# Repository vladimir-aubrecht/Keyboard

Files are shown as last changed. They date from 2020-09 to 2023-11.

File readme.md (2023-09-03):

# Keyboard overview
As usual, I started with this project because I couldn't find keyboard I'd like to use.

This project is trying to build following:
- :white_check_mark: TKL hotswap keyboard for Cherry MX switches.
- :white_check_mark: RGB LEDs under each switch (individually controllable from connected device).
- :white_check_mark: Bluetooth 5.0.
- :white_check_mark: Charging through USB-C.
- :construction: Anodized aluminium frame of Filco Majestouch 2 design.
- :white_check_mark: Part of case with connector is removable & replacable (to replace either connector or whole microcontroller for any other).

Side features:
- :white_check_mark: Except of sockets & connectors for connecting to MCU everything is on front side for soldering on JCLPCB side.
- :white_check_mark: Modularity - All logic chips are on separate modules. Main PCB contains just RGB LEDs, sockets and IO expanders with LED drivers.

❤️ I have some spare PCBs based on Revision 1 & 2. <br/>
**I will donate 1 piece of PCB per person** (develiry paid by you). Be aware, that it's just PCB, components must be soldered by you.

# Current status
[Revision 2](changelog.md) PCB is working, check details about the [rev 2 build](docs/revisions/rev2.md) and [manual](./docs/manual.md)!

I am finishing validation of adjusted casing and planning aluminium manufacturing soon.

If you are interested in more granular updates, I created [this Discord channel](https://discord.com/channels/1029883759740334140/1029884160967442452) where I'll be posting status, photos, ideas, etc.

## Achievements
- :zap: It's fast. In [Joltfly test](./docs/images/joltfly_rev_1.png) I got 0 ms latency. My internal measurements are 500 microseconds.
- :high_brightness: It's bright. RGB LED lights are well visible even during the daylight.

# Next steps
Polishing firmware is main focus. It's working, but there is a lot of technical debt there due to support of multiple microcontrollers for testing.
I started to work on [QMK support](https://github.com/vladimir-aubrecht/qmk_firmware/tree/xboard/keyboards/xboard).

For more details on long term plans you can check this [document](./docs/future.md).

TKL from top
TKL from detail

Check more [photos](./docs/gallery.md)! :)

# Credits

- [Jakub](https://www.printables.com/@null) for printing case for me on Prusa XL so I can have it in single piece :)

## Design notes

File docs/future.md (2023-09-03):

# Future plans

## Short term
### QMK
- Rev 1 keyboard is working now with QMK firmware, but bluetooth is not functional as when BT is enabled, keyboard scanning stop to work for some reason (will follow up on it).
- Rev 2 firmware in progress.

## Long term
- adding status LEDs or tiny colorful display (if I find some which fits into existing space, this is preferable solution).
- switch for turning keyboard on and off
- better microcontroller with USB-C and more program storage
- gyroscope / accelerometer for movement detection for optimizing wake up experience
- fingerprint sensor

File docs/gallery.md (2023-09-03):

# Galery

## Revision 2
Keyboard Top
TKL from top

Keyboard detail
TKL from detail

Numpad from angle
Numpad from angle

Numpad from top
Numpad from top

## Revision 1
Reality top cover
Case top cover

Reality top white LEDs
Case top white LEDs

Reality top colorfull LEDs
Case top colorfull LEDs

Reality back
Case back

Reality back connector
Case back connector

Keyboard
Keyboard

Reality front random colors
PCB reality front random colors

Reality front
PCB reality front

Render
Case render

Render no plate
case render no plate

Render no pcb
case render no pcb

Render no cover
case render no cover

Render front
PCB render front

Render back
PCB render back

Reality Plate
Plate reality

Render
Plate render

Scheme
PCB scheme

Reality front
PCB reality front

Reality back
PCB reality back

Reality numpad with LEDs on
PCB reality LEDs

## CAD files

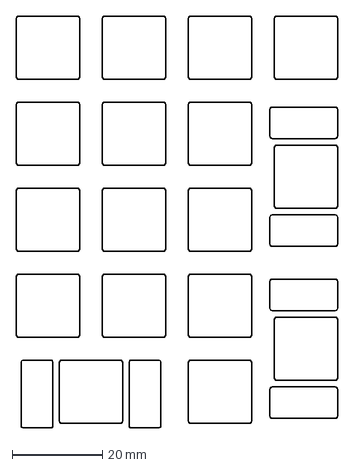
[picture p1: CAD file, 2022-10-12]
frame/numpad plate.dxf
71.1 x 91.2 mm

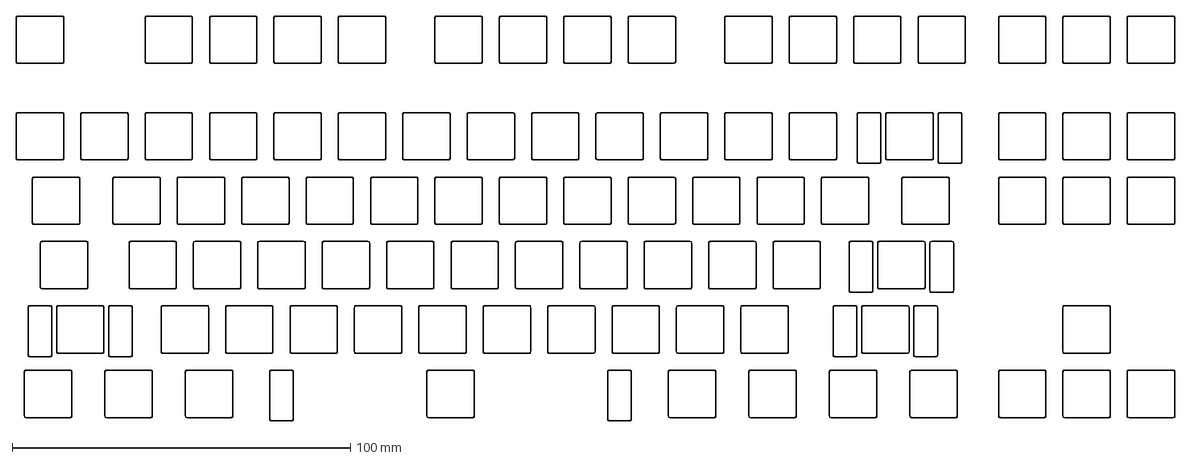
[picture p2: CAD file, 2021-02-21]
frame/plate.dxf
342.6 x 119.8 mm

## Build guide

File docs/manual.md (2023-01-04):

# Manual

## Bluetooth
For pairing the keyboard first [reset original pairing](#shortcuts), pair it with the device and then [switch to Bluetooth](#shortcuts).

Keyboard will be named as XBoard during the pairing.

When switching between USB and Bluetooth, you'll see which input channel is selected by blinking key.

<table>
    <tr>
        <th>Selected channel</th>
        <th><center>USB</center></th>
        <th><center>Bluetooth</center></th>
    </tr>
    <tr>
        <th>Key</th>
        <td>F1</td>
        <td>F2</td>
    </tr>
</table>

## Battery
Battery charge is visualised on Fkey line after pressing the [shortcut](#Shortcuts). Data will be shown as follow:

<table>
    <tr>
        <th>Key</th>
        <th><center>F1</center></th>
        <th><center>F2</center></th>
        <th><center>F3</center></th>
        <th><center>F4</center></th>
        <th><center>F5</center></th>
        <th><center>F6</center></th>
        <th><center>F7</center></th>
        <th><center>F8</center></th>
        <th><center>F9</center></th>
        <th><center>F10</center></th>
        <th><center>F11</center></th>
    </tr>
    <tr>
        <th>Battery [%]</th>
        <td>10</td>
        <td>20</td>
        <td>30</td>
        <td>40</td>
        <td>50</td>
        <td>60</td>
        <td>70</td>
        <td>80</td>
        <td>90</td>
        <td>100</td>
        <td>Keyboard is powered by USB</td>
    </tr>
</table>

When battery drops under 15%, then keyboard turns red.

## Shortcuts

| **Action** | **Shortcut** |
| :---: | :---: |
| Bluetooth Pairing Reset | Ctrl + Win + Esc |
| Toggle LED on/off | Ctrl + Win + F1  |
| Switch between USB / Bluetooth | Ctrl + Win + F2  |
| Randomize LEDs colors | Ctrl + Win + F3  |
| Show battery status | Ctrl + Win + F4  |

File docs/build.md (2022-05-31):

# Revisions

- [Revision 1](./revisions/rev1.md)
- [Revision 2](./revisions/rev2.md) (Work in progress)

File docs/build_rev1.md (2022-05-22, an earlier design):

# Build
This repository contains all necessary artefact to build the keyboard.

Meaning:
- PCB
- [List of components](#List-of-components)
- [Firmware](#Firmware) for [Adafruit Feather Bluefruit 32u4 LE](https://www.adafruit.com/product/2829) (read about [improvements](#future-improvements)!)
- [Plate](#Plate)
- Frame (not done yet)

> :warning: Revision 1 had originally bug with 2 swapped wires for power supply for IO expanders. That's why PCB in galery has those 2 wires and it was fixed in latest commits.

## Dimensions
- Plate: 343x119 mm
- PCB: 349x128 mm

## List of components for PCB
LCSC numbers are based on [JLCPCB](http://jlcpcb.com/) catalog.

| Type | Name | LCSC | Package | Amount | Description | 
| --- | --- | --- | --- | --- | --- |
| Diods | [1N4148WT](https://datasheet.lcsc.com/szlcsc/1908191708_MDD-Microdiode-Electronics-1N4148WT_C414017.pdf) | C414017 | SOD-523 |  87 | Preventing key ghosting & masking effects. |
| RGB LED | [19-237/R6GHBHC-A04/2T](https://datasheet.lcsc.com/szlcsc/2010222107_Everlight-Elec-19-237-R6GHBHC-A04-2T_C883183.pdf) | C883183 | 19-237  |  87 | Light under each switch. |
| IO Expanders | [MCP23017-E/SO](https://datasheet.lcsc.com/szlcsc/Microchip-Tech-MCP23017-E-SO_C47023.pdf) | C47023  | SOIC-28 | 2 | Connecting rows & columns from switch matrix through I2C. |
| LED Driver | [IS31FL3743A](https://cz.mouser.com/datasheet/2/198/IS31FL3743A_DS-1949512.pdf) | N/A | QFN-40  | 2 | Addressing LED and controlling RGB LED diods through I2C. |
| Hotswap sockets | [Kailh sockets](https://www.kailhswitch.com/info/kailh-switch-pcb-hot-swapping-socket-33463528.html) | N/A | N/A |  87 | Connecting Cherry MX switches |
| Stabilizers | [Cherry stabilizers](https://www.aliexpress.com/item/32951252318.html) | N/A | N/A | 5 | Stabilizing long keycaps. |
| Capacitor 1uF | [CL05A105KA5NQNC](https://datasheet.lcsc.com/szlcsc/Samsung-Electro-Mechanics-CL05A105KA5NQNC_C52923.pdf) | C52923  | 0402 | 4 | Stabilizing power circuit for LED drivers. |
| Resistor 10 KOhm  | [0402WGF1002TCE](https://datasheet.lcsc.com/szlcsc/Uniroyal-Elec-0402WGF1002TCE_C25744.pdf) | C25744  | 0402 | 6 | Controlling brightness & pull ups for IO expanders. |
| Resistor 4.7 KOhm | [0402WGF4701TCE](https://datasheet.lcsc.com/szlcsc/Uniroyal-Elec-0402WGF4701TCE_C25900.pdf) | C25900  | 0402 | 4 | Pull up resistor for LED drivers. |
| Resistor 200 Ohm  | [0402WGF2000TCE](https://datasheet.lcsc.com/szlcsc/Uniroyal-Elec-0402WGF2000TCE_C25087.pdf) | C25087  | 0402 |  12 | Green and blue LED channels to limit current and prevent overheating. |
| Resistor 150 Ohm  | [0402WGF1500TCE](https://datasheet.lcsc.com/szlcsc/Uniroyal-Elec-0402WGF1500TCE_C25082.pdf) | C25082  | 0402 | 6 | Red LED channel to limit current and prevent overheating. |

## Firmware
Custom made firmware (source code in repo) for [Adafruit Feather Bluefruit 32u4 LE](https://www.adafruit.com/product/2829). This has full feature set, keyboard functionality, RGB LEDs and Bluetooth are working.

Firmware is very simple to adjust (if needed at all) for other microcontrollers given microcontroller has required feature (USB HID, BT, I2C, 32 KB Program Storage - no need for all of them, you just need to comment USB HID or BT if your controller doesn't have it).

In Git history it's possible to find old version of firmware for QMK. It was working, but I don't maintain it anymore, thou it's possible to extend support if there will be enough of interest ...

## Plate
Built with the help of [Keyboard Layout Editor](http://www.keyboard-layout-editor.com/#/) & Keeb's Plate tool (https://plate.keeb.io/).

## Case
Built in OnShape CAD software, [check out](https://cad.onshape.com/documents/c60788452082993ff7acdd11/w/b14733d6a8d57351c8582e21/e/f5989423f9dc86a71831a4e9) the models!

## Future improvements
- Even thou RGB LED lights are working, **light intensity is quite low during the day light**. I am planning to play with global brightness resistor or switch to better LEDs.

- Adafruit Feather is working well, thou program storage is very limited - just 32 KB. Current version of firmware is using all of that and I had to comment out logging as didn't have enough of storage. It can be probably optimised more, my guess is to like 50-75% of current usage, but it will still be tight for more new features. I'll be switching to better microcontroller...

- Current combination of PCB chips is limiting I2C to 400 KHz and given amount of queries to MCP23017 there is a performance issue there. Latency of scanning is ~20 ms, **total latency ~30 ms** (through USB). Feeling wise I didn't have problem to type on it by using all my 10 fingers with quite fast speed, but I can imagine it might be **problematic for progamers**. Potential workaround around this is disconnecting RGB LEDs through the connector after which 1.7MHz on I2C should be available, potentially speeding it up.
In next version I am planning to switch to SPI.

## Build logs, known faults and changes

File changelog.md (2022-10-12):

All prices below are based 5 pieces (minimum) on: [JLCPCB](https://jlcpcb.com/).

# Keyboard revison 2 (PCB: $22.34, SMT: $77.29 work in progress)
- PCB based on Rev 1 features, added:
  - ⭐ Switch matrix is driven by IO expanders through SPI to achieve <1 ms end to end latencies.
  - ⭐ Heavily increased brightness of all LEDs by having separate LED driver for each 2 columns (due to max current per chip).
  - ⭐ Fixed bug with swapped GND and VCC, no more bridging needed.
- TKL Case
  - ⭐ Added support for magnetically attachable numpad from left or right by inserting magnets into prepared sockets.
    - I recommend N52 magnets, with those connection is strong enough to lift numpad part into air :)
    - I used these [magnets 20x5x2](https://www.aliexpress.com/item/1005001646834539.html?spm=a2g0o.order_list.0.0.25271802ZhGVrg) from exactly this store. I had bad experience with some other sellers as quality of magnets were lower than advertised.
    - You need 18 magnets in total for TKL keyboard (and another 18 for numpad).
- Numpad Case
  - ⭐ Created magnetically attachable numpad! :)
    - Similar design like main TKL keyboard (just without internal pillars for extra support)
    - Requires it's own microcontroller and battery in case of bluetooth usage.
    - Top part of numpad is kept empty for this moment - work in progress, meant for display and fingerprint sensor.

# Keyboard revison 1 (PCB: $21.8, SMT: $30.56)
- PCB based on revision 0 features, added:
  - ⭐ Switch matrix is driven by IO expanders through I2C.
  - ⭐ Added RGB leds to every switch
    - Each LED's color configurable separately.
    - Controlled by built-in LED driver controlled through I2C.
  - 💪🏻 All solderable [JLCPCB](https://jlcpcb.com/) library components for assembly are moved to top side.
  - 💪🏻 Increased clearances.
  - 🤜🏻 Collisions of diods with stabilizers are fixed.
  - :exclamation: Contains bug with powering MCP23017 chips (GND and VCC are swapped - can be easily fixed by bridging with 2 wires and some scratching :) )

# Keyboard revision 0 (PCB: $22.1, SMT: N/A)
- ⭐ TKL matrix for Cherry MX switches.
- ⭐ Holes for stabilizers.

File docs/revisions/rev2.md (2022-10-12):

# Build Revision 2 (Work in progress!!!)
This repository contains all necessary artefact to build the keyboard.

Meaning:
- PCB
- [List of components](#List-of-components)
- [Firmware](#Firmware)
- [Plate](#Plate)
- Frame (not done yet)

## Dimensions
- Plate: 343x119 mm
- PCB: 349x128 mm

## List of components
LCSC numbers are based on [JLCPCB](http://jlcpcb.com/) catalog.

| Type | Name | LCSC | Package | Amount | Description | 
| --- | --- | --- | --- | --- | --- |
| IO Expanders | [MAX7301ATL+](https://jlcpcb.com/partdetail/MaximIntegrated-MAX7301ATL/C1522600) | C1522600 | QFN50P600X600X80-41N | 1 | Connecting rows & columns from switch matrix through SPI. |
| I2C Multiplexer | [TCA9548ARGER](http://www.ti.com/lit/ds/symlink/tca9548a.pdf) | C555456  | VQFN-24 | 1 | Multiplexing communication with LED drivers. |
| C 47 nF | [CC0402KRX5R9BB473](https://datasheet.lcsc.com/lcsc/2003312232_YAGEO-CC0402KRX5R9BB473_C505502.pdf) | C505502  | 0402 | 1 | Power stabilization. |
| C 100 nF | [CL05A105KA5NQNC](https://datasheet.lcsc.com/lcsc/1811091611_Samsung-Electro-Mechanics-CL05A105KA5NQNC_C52923.pdf) | C52923 | 0402 | 9 | Power stabilization. |
| C 1 uF | [CL05B104KO5NNNC](https://datasheet.lcsc.com/lcsc/1810191219_Samsung-Electro-Mechanics-CL05B104KO5NNNC_C1525.pdf) | C1525 | 0402 | 6 | Power stabilization. |
| Diods | [1N4148WT](https://datasheet.lcsc.com/szlcsc/1908191708_MDD-Microdiode-Electronics-1N4148WT_C414017.pdf) | C414017  | SOD-523 |  87 | Preventing key ghosting & masking effects. |
| Resistor 10 KOhm  | [0402WGF1002TCE](https://datasheet.lcsc.com/szlcsc/Uniroyal-Elec-0402WGF1002TCE_C25744.pdf) | C25744 | 0402 |  19 | Controlling brightness & pull ups for IO expanders. |
| Resistor 39 KOhm  | [0402WGF3902TCE](https://datasheet.lcsc.com/lcsc/2206010100_UNI-ROYAL-Uniroyal-Elec-0402WGF3902TCE_C25783.pdf) | C25783 | 0402 | 1 | Controlling brightness |
| RGB LED | [19-237/R6GHBHC-A04/2T](https://datasheet.lcsc.com/szlcsc/2010222107_Everlight-Elec-19-237-R6GHBHC-A04-2T_C883183.pdf) | C883183  | 19-237 |  87 | Light under each switch. |
| LED Driver | [IS32FL3746B](https://www.lumissil.com/assets/pdf/core/IS32FL3746B_DS.pdf) | C2678953 | WFQFN-32 | 9 | Addressing LED and controlling RGB LED diods through SPI. |
| Stabilizers | [Cherry stabilizers](https://www.aliexpress.com/item/32951252318.html) | N/A | N/A | 5 | Stabilizing long keycaps. |
| Hotswap sockets | [Kailh sockets](https://www.kailhswitch.com/info/kailh-switch-pcb-hot-swapping-socket-33463528.html) | C2803348 | SMAD |  87 | Connecting Cherry MX switches |

## Firmware
Firmware is custom made in this [repo](../../firmware/Custom/), thou there is nothing preventing using QMK firmware if support for this keyboard is added. I might add it in the future, currently it's not in my focus as I am focusing on hardware finalization first.

## Plate
Built with the help of [Keyboard Layout Editor](http://www.keyboard-layout-editor.com/#/) & Keeb's Plate tool (https://plate.keeb.io/).

## Case
Built in OnShape CAD software, [check out](https://cad.onshape.com/documents/c60788452082993ff7acdd11/w/b14733d6a8d57351c8582e21/e/f5989423f9dc86a71831a4e9) the models!

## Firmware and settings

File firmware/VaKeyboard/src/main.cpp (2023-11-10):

#include <Arduino.h>
#include "Logger.h"

#if defined(NUMPAD) && defined(V2)
#include "Drivers/Numpad/V2/KeyboardSDK.h"
#endif

#if defined(TKL) && defined(V1)
#include "Drivers/TKL/V1/KeyboardSDK.h"
#endif

#if defined(TKL) && defined(V2)
#include "Drivers/TKL/V2/KeyboardSDK.h"
#endif

#include "Features/BluetoothFeature.h"
#include "Features/RGBLedFeature.h"

KeyboardSDK* keyboardSDK = NULL;

void setup()
{
	delay(2000); // Keep the delay. It's useful when program crashes during the setup as you can reflash program without the need of pressing RESET button.

	Serial.begin(115200);
	Wire.begin();

	keyboardSDK = new KeyboardSDK(McuConfig::csPin, McuConfig::mosiPin, McuConfig::sclkPin, McuConfig::misoPin, &Wire, new Logger());
	auto rgbLedFeature = new RGBLedFeature(keyboardSDK);
	auto bluetoothFeature = new BluetoothFeature(keyboardSDK);

	auto macroEvaluator = keyboardSDK->GetMacroEvaluator();
	macroEvaluator->registerFeature(rgbLedFeature);
	macroEvaluator->registerFeature(bluetoothFeature);
}

void loop()
{
	keyboardSDK->GetKeyPressProcessor()->scan();

	uint8_t batteryLevel = keyboardSDK->GetBatteryDriver()->readBatteryLevel();

	if (batteryLevel < 15)
	{
		keyboardSDK->GetRGBLedDriver()->setColor(0, 0, 0xff, 0, 0);
	}
}

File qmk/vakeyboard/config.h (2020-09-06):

#pragma once

#include "config_common.h"

/* USB Device descriptor parameter */
#define VENDOR_ID       0xFEED
#define PRODUCT_ID      0x2040
#define DEVICE_VER      0x0001
#define MANUFACTURER    Vladimir Aubrecht
#define PRODUCT         vakeyboard
#define DESCRIPTION     VA Keyboard

/* key matrix size */
#define MATRIX_ROWS 6
#define MATRIX_COLS 18

/* key matrix pins */
#define MATRIX_ROW_PINS { F7, F6, F5, F4, F1, F0 }
#define MATRIX_COL_PINS { D6, B7, B6, B5, B4, E6, D7, C6, D4, D0, D1, C7, C7, C7, C7, C7, C7, C7 }
#define UNUSED_PINS

/* COL2ROW or ROW2COL */
#define DIODE_DIRECTION COL2ROW

/* number of backlight levels */

#ifdef BACKLIGHT_PIN
#define BACKLIGHT_LEVELS 0
#endif

/* Set 0 if debouncing isn't needed */
#define DEBOUNCE 5

/* Mechanical locking support. Use KC_LCAP, KC_LNUM or KC_LSCR instead in keymap */
#define LOCKING_SUPPORT_ENABLE

/* Locking resynchronize hack */
#define LOCKING_RESYNC_ENABLE

#ifdef RGB_DI_PIN
#define RGBLIGHT_ANIMATIONS
#define RGBLED_NUM 0
#define RGBLIGHT_HUE_STEP 8
#define RGBLIGHT_SAT_STEP 8
#define RGBLIGHT_VAL_STEP 8
#endif

/* disable these deprecated features by default */
//#define NO_ACTION_MACRO
//#define NO_ACTION_FUNCTION
#define NO_ACTION_TAPPING

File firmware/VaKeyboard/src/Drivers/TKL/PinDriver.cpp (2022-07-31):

#ifdef TKL

#include "PinDriver.h"

void PinDriver::refreshCache()
{
	uint32_t banks = 0;
	banks |= ((uint16_t)(~mcp0->readGPIOB())) << 8;
	banks |= ((uint32_t)~mcp1->readGPIOAB()) << 16;
	cache = banks;
}

uint8_t PinDriver::readPin(uint8_t pinNumber)
{
	if (pinNumber < 8)
	{
		uint32_t mask = (1 << (7 - pinNumber));
		return (((cache << 16) >> 24) & mask) >> (7 - pinNumber);
	}
	else if (pinNumber < 16)
	{
		uint32_t mask = (1 << (7 - (pinNumber - 8)));
		return ((cache >> 16) & mask) >> (7 - (pinNumber - 8));
	}
	else
	{
		uint32_t mask = (1 << (15 - (pinNumber - 16)));
		return ((cache >> 16) & mask) >> (15 - (pinNumber - 16));
	}
}

void PinDriver::writePin(uint8_t pinNumber, uint8_t value)
{
	mcp0->digitalWrite(pinNumber, value);
}

PinDriver::PinDriver(TwoWire *wire, ILogger *logger)
{
	//this->logger = logger;
	uint8_t mcp0Status = mcp0->begin_I2C((uint8_t)MCP23XXX_ADDR, wire);

	if (!mcp0Status)
	{
		// this->logger->logError(F("Failed to initialise first MCP23017."));
		return;
	}

	for (uint8_t i = 0; i < 8; i++)
	{
		mcp0->pinMode(i, OUTPUT);
	}

	for (uint8_t i = 8; i < 16; i++)
	{
		mcp0->pinMode(i, INPUT_PULLUP);
	}

	uint8_t mcp1Status = mcp1->begin_I2C((uint8_t)MCP23XXX_ADDR + 7, wire); // outside chip next to keyboard edge

	if (!mcp1Status)
	{
		// this->logger->logError(F("Failed to initialise second MCP23017."));
		return;
	}

	for (uint8_t i = 0; i < 8; i++)
	{
		mcp1->pinMode(i, INPUT_PULLUP);
	}

	for (uint8_t i = 8; i < 16; i++)
	{
		mcp1->pinMode(i, INPUT_PULLUP);
	}
}

#endif

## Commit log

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2020-12-19 Redoing pcb from scratch with scheme.
    [keyboard.kicad_pcb, vakeyboard.kicad_pcb, vakeyboard.sch]
2020-12-19 Draw all tracks except of connector tracks
    [vakeyboard.kicad_pcb]
2020-12-20 Ugly, but everything is connected.
    [vakeyboard.kicad_pcb]
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2020-12-27 PCB is now connected through I2C only and all RGB leds are fully controllable.
    [vakeyboard.kicad_pcb, vakeyboard.sch]
2020-12-27 Switch to common cathode diods.
    [vakeyboard.kicad_pcb, vakeyboard.sch]
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2021-01-22 Redesigned in a way it's using 2 expanders.
    [config.h]
2021-01-26 Adjusted size of PCB rev 1.
    [vakeyboard.kicad_pcb, vakeyboard.scad]
2021-01-27 First non finished draft of plate.
    [vakeyboard.scad]
2021-01-27 Fixed horizontal alignment for frame.
    [vakeyboard.scad]
2021-01-27 Finished first hot draft of plate and starting with rewrite.
    [vakeyboard.scad, vakeyboard2.scad]
2021-02-04 Added new version of PCB, not finished yet.
    [vakeyboard.kicad_pcb, vakeyboard.sch]
2021-02-04 First IO expander is rotated now.
    [vakeyboard.kicad_pcb]
2021-02-04 Redefined clearance to minimize crosstalk.
    [vakeyboard.kicad_pcb]
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2021-02-04 Updated readme and schematics in a way it's possible to export BOM file and PCR file so JLCPCB can solder it.
    [vakeyboard.kicad_pcb, vakeyboard.sch]
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2021-02-04 Hidden all references and values for diods.
    [vakeyboard.sch]
2021-02-04 Initial scheme for RGB led matrix.
    [vakeyboard.sch]
2021-02-04 Added first connections between RGB leds.
    [vakeyboard.sch]
2021-02-05 All RGB leds are connected to the matrix.
    [vakeyboard.sch]
2021-02-05 All RGB leds renamed.
    [vakeyboard.sch]
2021-02-05 RGB leds added into footprint but still out of keyboard.
    [vakeyboard.kicad_pcb, vakeyboard.sch]
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2021-02-05 Fixed keycap dimensions.
    [vakeyboard.kicad_pcb]
2021-02-06 Added RGB leds under every switch.
    [vakeyboard.kicad_pcb, vakeyboard.sch]
2021-02-06 Added symbol for IS31FL3743A driver.
    [vakeyboard.kicad_pcb, vakeyboard.sch]
2021-02-06 LED drivers added into board.
    [vakeyboard.kicad_pcb, vakeyboard.sch]
2021-02-07 Everything connected, added footprints, not positioned yet.
    [vakeyboard.kicad_pcb, vakeyboard.sch]
2021-02-07 Most new components categorized.
    [vakeyboard.kicad_pcb, vakeyboard.sch]
2021-02-07 Added tracks for rows and half of leds in rows direction.
    [vakeyboard.kicad_pcb]
2021-02-07 Connected first 3 columns for leds.
    [vakeyboard.kicad_pcb]
2021-02-07 Finished all columns track for first led driver.
    [vakeyboard.kicad_pcb]
2021-02-07 Added tracks for first half of rows for LED diods.
    [vakeyboard.kicad_pcb]
2021-02-07 Fixed footprints assignments.
    [vakeyboard.kicad_pcb, vakeyboard.sch]
2021-02-08 Last 3 columns of LEDs are missing to connect.
    [vakeyboard.kicad_pcb, vakeyboard.sch]
2021-02-09 Reverted to disconnected chips and fixed issues in the scheme.
    [vakeyboard.kicad_pcb, vakeyboard.sch]
2021-02-09 Track size reduced to 0.2 mm.
    [vakeyboard.kicad_pcb]
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2021-02-09 Used smaller resistors for leds.
    [vakeyboard.kicad_pcb, vakeyboard.sch]
2021-02-09 Used physically smaller capacitors.
    [vakeyboard.kicad_pcb, vakeyboard.sch]
2021-02-09 Reconfigured sizes of tracks and vias based on jlcpcb to reach smaller sizes.
    [vakeyboard.kicad_pcb]
2021-02-09 Fixed checks.
    [vakeyboard.kicad_pcb]
2021-02-09 Columns are connected into first led driver.
    [vakeyboard.kicad_pcb]
2021-02-09 Resistors moved closer to led driver.
    [vakeyboard.kicad_pcb]
2021-02-14 Updated footprint of led driver.
    [vakeyboard.kicad_pcb]
2021-02-14 Connection of RGB leds is nicer now.
    [vakeyboard.kicad_pcb]
2021-02-14 All rows have tracks close to left led driver.
    [vakeyboard.kicad_pcb]
2021-02-15 Deleted all connections to LED driver.
    [vakeyboard.kicad_pcb]
2021-02-15 Connected all rows to LED driver.
    [vakeyboard.kicad_pcb]
2021-02-15 First LED driver connected except of columns.
    [vakeyboard.kicad_pcb]
2021-02-15 Fixed errors for clearance 0.2mm.
    [vakeyboard.kicad_pcb]
2021-02-15 Clearance increased to 2.1mm
    [vakeyboard.kicad_pcb]
2021-02-15 All columns connected to left LED driver.
    [vakeyboard.kicad_pcb]
2021-02-15 Started with positioning of second led driver.
    [vakeyboard.kicad_pcb]
2021-02-15 Connected first few rows to second led driver.
    [vakeyboard.kicad_pcb]
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2021-02-16 Second led driver connected all rows and columns
    [vakeyboard.kicad_pcb]
2021-02-16 Fixed sync connection.
    [vakeyboard.kicad_pcb, vakeyboard.sch]
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2021-02-16 Bottom row diods moved to front side (pcb can be soldered only from one side by JLCPCB).
    [vakeyboard.kicad_pcb]
2021-02-16 Another rows diods moved to front. Disconnected all diods on the back.
    [vakeyboard.kicad_pcb]
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2021-02-17 Connected all diods on all rows except of first one.
    [vakeyboard.kicad_pcb]
2021-02-17 All diods are now soldered from the front.
    [vakeyboard.kicad_pcb]
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2021-02-17 Fixed DRC errors.
    [vakeyboard.kicad_pcb]
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2021-02-21 F row moved 2.57 mm towards top edge to match plate.
    [vakeyboard.kicad_pcb]
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2021-02-21 Fixed most of DRC errors.
    [vakeyboard.kicad_pcb]
2021-02-21 Adjusted clearances.
    [vakeyboard.kicad_pcb]
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2021-03-01 Updated docs and conflict of diods with stabilizers
    [vakeyboard.kicad_pcb, vakeyboard.sch]
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2021-04-02 Fixed bug with overflow on 16th column.
    [PinDriver.cpp]
2021-07-25 Fixed bug with powering MCP23017 (swapped ground and voltage)
    [vakeyboard.kicad_pcb, vakeyboard.sch]
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2021-08-26 Code is not crashing when one of the circuits is not connected.
    [Is31fl3743a.cpp, PinDriver.cpp]
2022-01-10 Project is now buildable also for ESP32, thou USB HID doesn't work now with ESP32 and BT is added, but not tested.
    [Is31fl3743a.cpp]
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2022-05-15 Added possibility to reset BT pairing by keyboard shortcut.
    [PinDriver.cpp, main.cpp]
2022-05-15 Added shortcuts for toggling LEDs and connection type.
    [Is31fl3743a.cpp, main.cpp]
2022-05-15 Added shortcut for randomizing colors on keyboard.
    [Is31fl3743a.cpp, PinDriver.cpp, main.cpp]
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2022-05-20 Added light effect for feedback when switching devices and possibility to show battery status. Commented all error messages as I don't have enough of flash storage for them... :-/
    [Is31fl3743a.cpp, PinDriver.cpp, main.cpp]
2022-05-20 Uncommented few error messages.
    [Is31fl3743a.cpp, Logger.cpp, PinDriver.cpp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]
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2022-05-21 - Added battery status when connected through BT. - Fixed issue of holden key when switching between connections. - Disabled logging (temporary) - Adjusted reporting of battery levels.
2022-05-25 Fixed crash when pressing shortcuts.
    [Is31fl3743a.cpp, main.cpp]
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2022-05-29 WIP transit of LED controllers to 9 SPI controllers.
    [vakeyboard.kicad_sch]
2022-05-30 Schema communicates through SPI and using 9 led drivers now.
    [vakeyboard.kicad_sch]
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2022-06-09 Fixed bug + more tracks
    [vakeyboard.kicad_pcb, vakeyboard.kicad_sch]
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2022-06-11 Fixed bug with SDB pin connected to ground instead of VCC
    [vakeyboard.kicad_pcb, vakeyboard.kicad_sch]
2022-06-11 Fixed DRCs
    [vakeyboard.kicad_pcb, vakeyboard.kicad_sch]
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2022-06-12 Updated symbol deleted by mistake
    [vakeyboard.kicad_sch]
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2022-06-13 Fixed library bugs
    [vakeyboard.kicad_pcb, vakeyboard.kicad_sch]
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2022-06-13 Added second LED controller for higher current per LED
    [Numpad.kicad_pcb, Numpad.kicad_sch]
2022-06-14 Removed several capacitors to decrease current consumption on startup
    [Numpad.kicad_pcb, vakeyboard.kicad_pcb, vakeyboard.kicad_sch]
2022-06-15 Added more tracks to numpad and positioned LED controllers
    [Numpad.kicad_pcb]
2022-06-17 Fixed constraints
    [Numpad.kicad_pcb, vakeyboard.kicad_pcb]
2022-06-18 Switch from mcp23S17 to Max7301 due to supply issues + it saves space.
    [vakeyboard.kicad_pcb, vakeyboard.kicad_sch]
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2022-06-21 Fixed errors in DRC for PCB
    [Numpad.kicad_pcb]
2022-06-21 Fixed fields
    [Numpad.kicad_sch]
2022-06-21 Modified footprint for LEDs, so they have right rotation for pick and place
    [BOM-Numpad.csv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]
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2022-07-09 Reverted quotes in header
    [Numpad.csv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]
2022-07-11 Solved conflict of resistor with switch
    [Numpad-B_Cu.gbl, Numpad-B_Mask.gbs, Numpad-B_Paste.gbp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]
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2022-07-31 Fixed building for feather32u4.
    [Is31fl3743a.cpp, PinDriver.cpp, main.cpp]
2022-07-31 Fixed compilation for Portenta H7
    [main.cpp]
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2022-08-06 - Added support for volume keys by switching layers through context key. - RAM optimizations - Fixed memory leak in ActionEvaluator - Added delay for startup of keyboard to avoid need of pressing res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
    [main.cpp]
2022-08-06 - Fixed media keys for USB connection for feather, now it works on all OS and supports also Next/Previous/Play&Pause buttons. - Broke volume keys for BT connection. - Possibly broke builds for other 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
    [main.cpp]
2022-08-06 Fixes for arduino micro
    [Is31fl3743a.cpp]
2022-08-14 Added compilable, but not working support for TinyS3.
    [main.cpp]
2022-10-09 Fixed shortcuts for numpad.
    [main.cpp]
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2022-10-12 Fixed assembly files
    [vakeyboard.kicad_pcb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]
2022-10-14 Firmware can be now compiled (but not working) for Feather ESP32-S3
    [main.cpp]
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2023-01-03 Fixed functionality for feather32u4 tkl v1
    [Is31fl3743a.cpp, PinDriver.cpp, main.cpp]
2023-03-27 Added protection against stucking (if loop will get slower than 500ms, mcu will get restarted)
    [main.cpp]
2023-03-27 hid report must be sent only when it's changed, otherwise mcu will get stuck for some reason ...
    [main.cpp]
2023-04-04 Introduced concept of features for cleanup, but not final as I need to investigate on how to replace function pointers in ActionEvaluator
    [main.cpp]
2023-04-07 Replacement of ActionEvalutor for MacroEvaluator.
    [main.cpp]
2023-06-30 Fixed non-1u keys, they were missing holes for stabilizators in TKL version.
    [vakeyboard.kicad_pcb]
2023-08-13 MOSI pin changed to 38 on TinyS2 due to case design to prevent collission.
2023-08-15 Fixes for RGB leds.
    [main.cpp]
2023-09-03 Fixed crashes and code cleanup.
    [main.cpp]
2023-09-05 - Fixed bug with BT not working after refactor. - Fixed bug with preserving LED states (except of automatic wake up). - Added partial BT support for TinyS3 (not working properly yet, but at least can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
